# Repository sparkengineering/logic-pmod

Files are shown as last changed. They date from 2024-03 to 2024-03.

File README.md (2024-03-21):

# logic-pmod




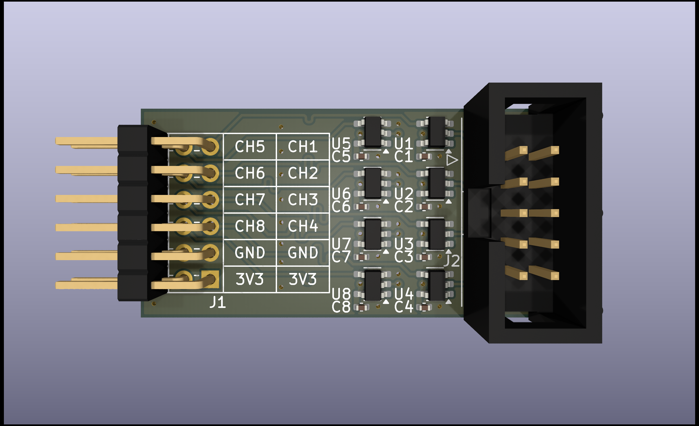
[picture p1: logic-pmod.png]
3D render of this Pmod level shifter board


## Description

Logic level shifter with Digilent Pmod™ interface for use as logic analyzer.

- 8 fixed direction, length tuned, level shifting channels
- Up/down translation from 1.8V, 2.5V, 5V to 3.3V
- Bus Pirate probe cable compatible 10-pin connector

## Contents

| File | Description |
|---|---|
| [logic-pmod.pdf](./logic-pmod.pdf) | Schematic in PDF format |
| [logic-pmod.csv](./logic-pmod.csv) | BOM in CSV format |
| [logic-pmod.png](./logic-pmod.png) | PCB 3D render |
| | |
| [logic-pmod.kicad_pro](./logic-pmod.kicad_pro) | KiCad 8.0.0 project |
| [logic-pmod.kicad_pcb](./logic-pmod.kicad_pcb) | KiCad 8.0.0 PCB |
| [logic-pmod.kicad_sch](./logic-pmod.kicad_sch) | KiCad 8.0.0 schematic |

## Probe Pinout

| Pin | Color  | Net  |
|-----|---|---|
| 1 | Brown  | GND  |
| 2 | Red | +3V3 |
| | | |
| 3 | Orange | CH5  |
| 4 | Yellow | CH1  |
| 5 | Green  | CH6  |
| 6 | Blue | CH2  |
| 7 | Purple | CH7  |
| 8 | Grey | CH3  |
| 9 | White  | CH8  |
|  10 | Black  | CH4  |

## Further Reading

- FPGA Logic Analyzer and GUI [^1]
- Small footprint and configurable embedded FPGA logic analyzer [^2]
- Integrated Logic Analyzer (ILA) [^3]

[^1]: https://github.com/lekgolo167/enxor-logic-analyzer
[^2]: https://github.com/enjoy-digital/litescope
[^3]: https://www.xilinx.com/products/intellectual-property/ila.html

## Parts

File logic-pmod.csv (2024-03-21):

Reference | Value | Footprint | Qty | DNP | MFG | MPN | OC_Mouser | OC_LCSC
C1,C2,C3,C4,C5,C6,C7,C8 | 100nF | Capacitor_SMD:C_0402_1005Metric | 8 |  | Murata Electronics | GRM155R61A104JA01D | 81-GRM155R61A104JA1D | C177144
J1 | Conn_02x06_Odd_Even | logic-pmod:PinHeader_2x06_P2.54mm_Horizontal | 1 |  | TE Connectivity | 826634-6 | 571-826634-6 | ~
J2 | Conn_02x05_Odd_Even | logic-pmod:IDC-Header_2x05_P2.54mm_Vertical | 1 |  | TE Connectivity | 1761681-3 | 571-1761681-3 | C573025
U1,U2,U3,U4,U5,U6,U7,U8 | SN74LV1T34DBV | Package_TO_SOT_SMD:SOT-23-5 | 8 |  | Texas Instruments | SN74LV1T34QDBVRQ1 | 595-N74LV1T34QDBVRQ1 | ~

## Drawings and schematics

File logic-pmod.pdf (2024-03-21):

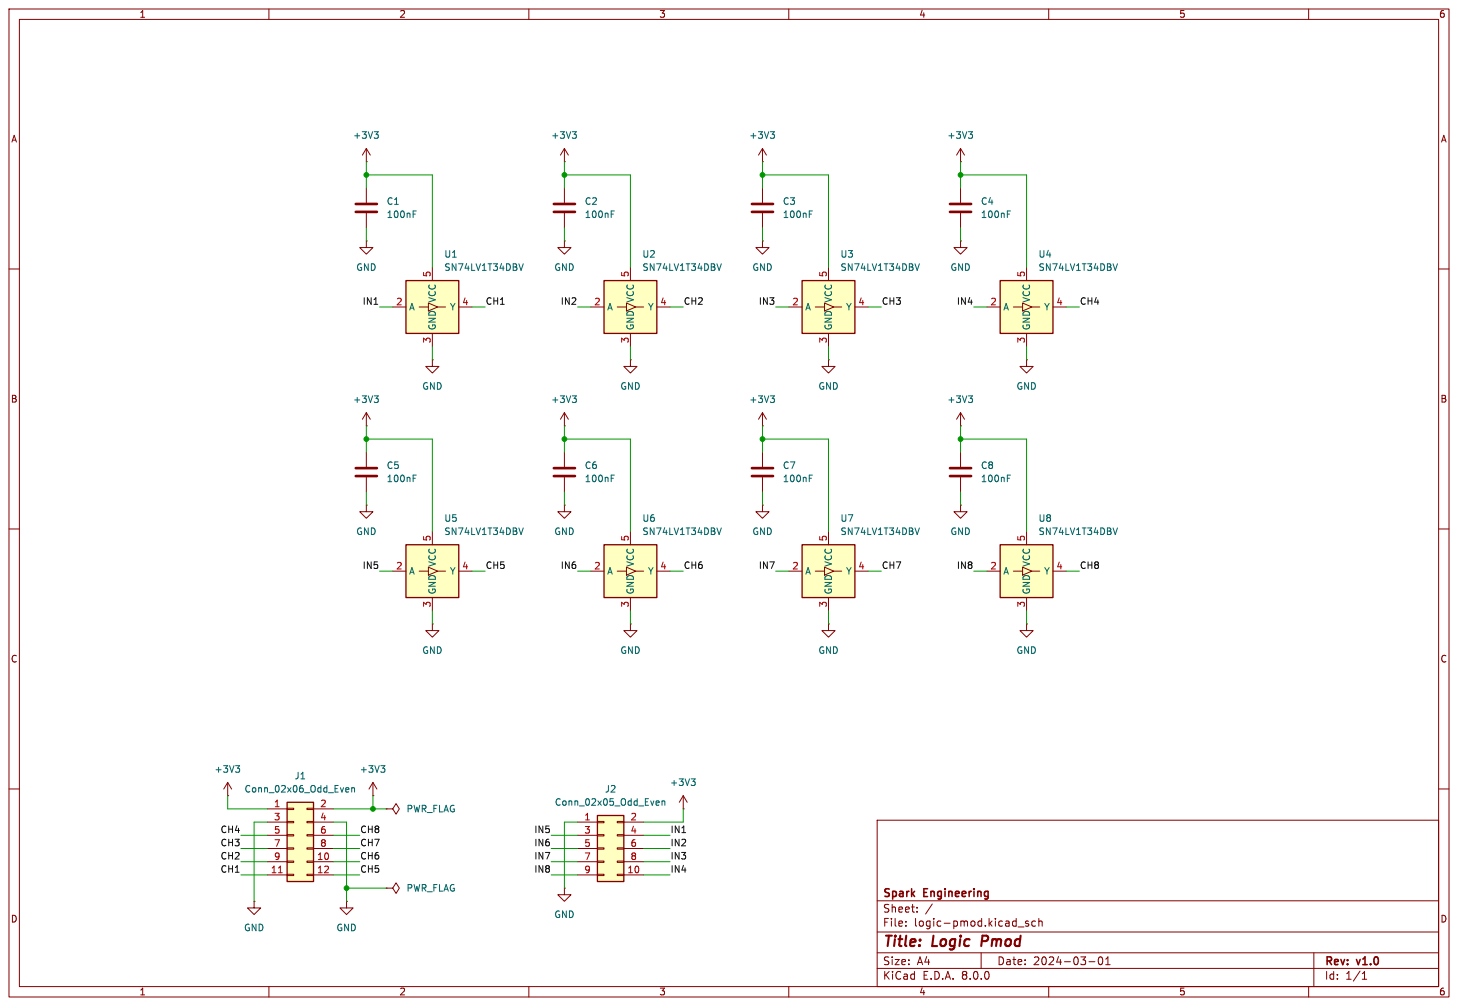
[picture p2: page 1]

5 U7SN74LV1T34DBV GND GND GND GND

Id: 1/1 Title: Logic Pmod

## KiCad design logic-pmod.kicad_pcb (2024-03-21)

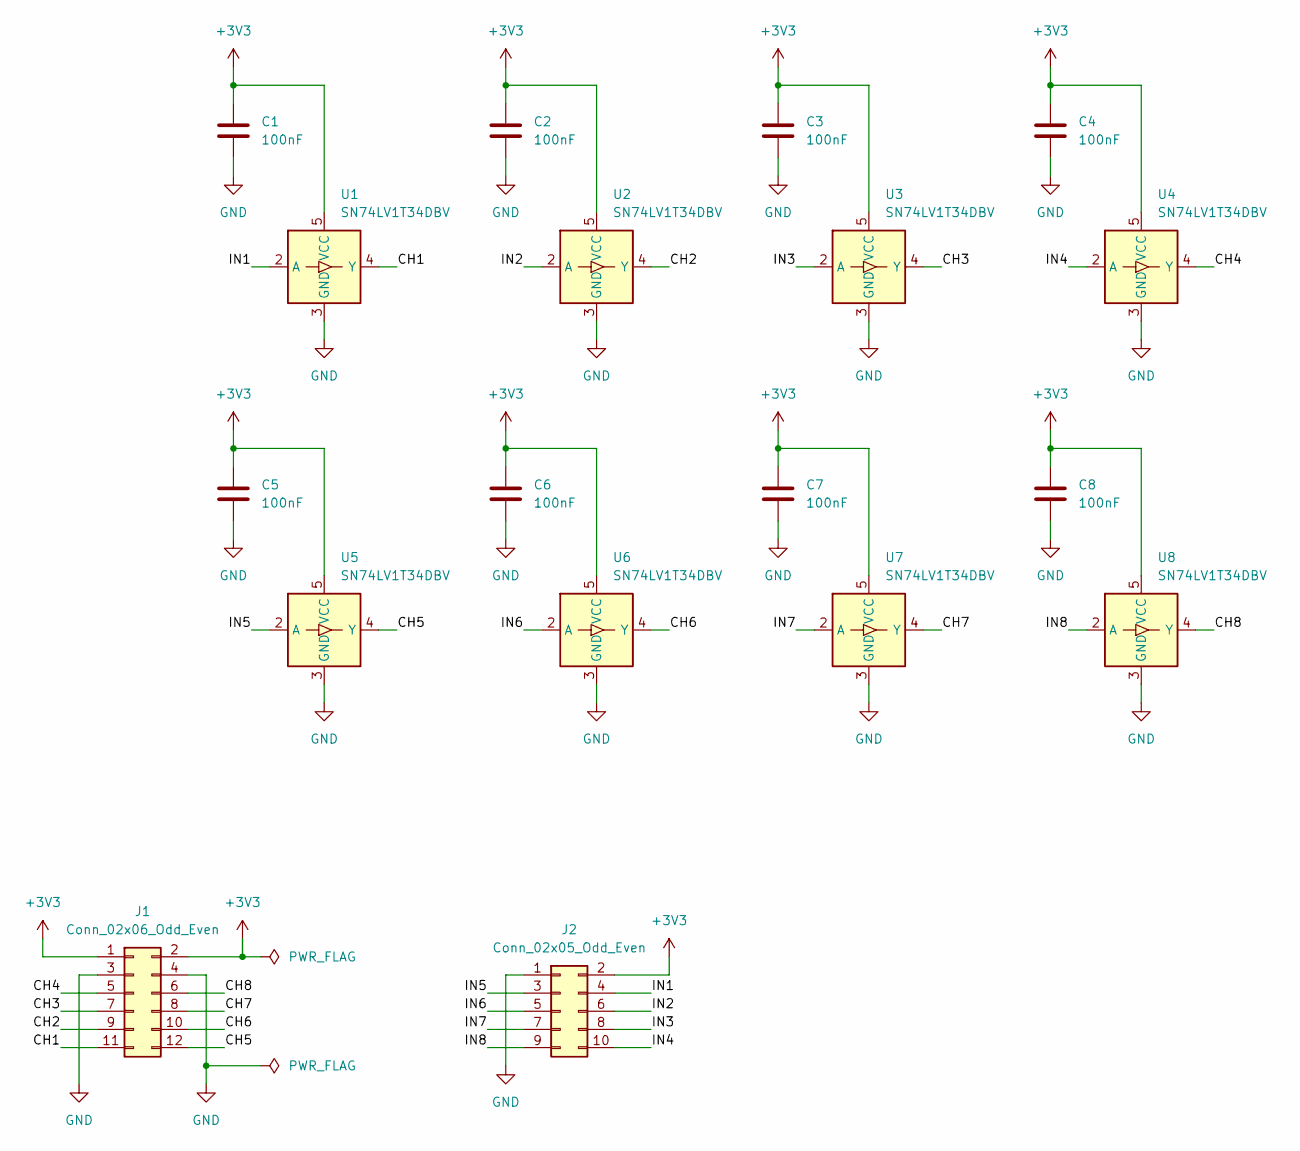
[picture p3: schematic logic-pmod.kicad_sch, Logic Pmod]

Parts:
C1, C2, C3, C4, C5, C6, C7, C8: 100nF; C_0402_1005Metric; MPN GRM155R61A104JA01D
J1: Conn_02x06_Odd_Even; PinHeader_2x06_P2.54mm_Horizontal; MPN 826634-6
J2: Conn_02x05_Odd_Even; IDC-Header_2x05_P2.54mm_Vertical; MPN 1761681-3
U1, U2, U3, U4, U5, U6, U7, U8: SN74LV1T34DBV; SOT-23-5; MPN SN74LV1T34QDBVRQ1

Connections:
+3V3: C1.1, C2.1, C3.1, C4.1, C5.1, C6.1, C7.1, C8.1, J1.1, J1.2, J2.2, U1.5 (VCC), U2.5 (VCC), U3.5 (VCC), U4.5 (VCC), U5.5 (VCC), U6.5 (VCC), U7.5 (VCC), U8.5 (VCC)
/CH1: J1.11, U1.4 (Y)
/CH2: J1.9, U2.4 (Y)
/CH3: J1.7, U3.4 (Y)
/CH4: J1.5, U4.4 (Y)
/CH5: J1.12, U5.4 (Y)
/CH6: J1.10, U6.4 (Y)
/CH7: J1.8, U7.4 (Y)
/CH8: J1.6, U8.4 (Y)
/IN1: J2.4, U1.2 (A)
/IN2: J2.6, U2.2 (A)
/IN3: J2.8, U3.2 (A)
/IN4: J2.10, U4.2 (A)
/IN5: J2.3, U5.2 (A)
/IN6: J2.5, U6.2 (A)
/IN7: J2.7, U7.2 (A)
/IN8: J2.9, U8.2 (A)
GND: C1.2, C2.2, C3.2, C4.2, C5.2, C6.2, C7.2, C8.2, J1.3, J1.4, J2.1, U1.3 (GND), U2.3 (GND), U3.3 (GND), U4.3 (GND), U5.3 (GND), U6.3 (GND), U7.3 (GND), U8.3 (GND)

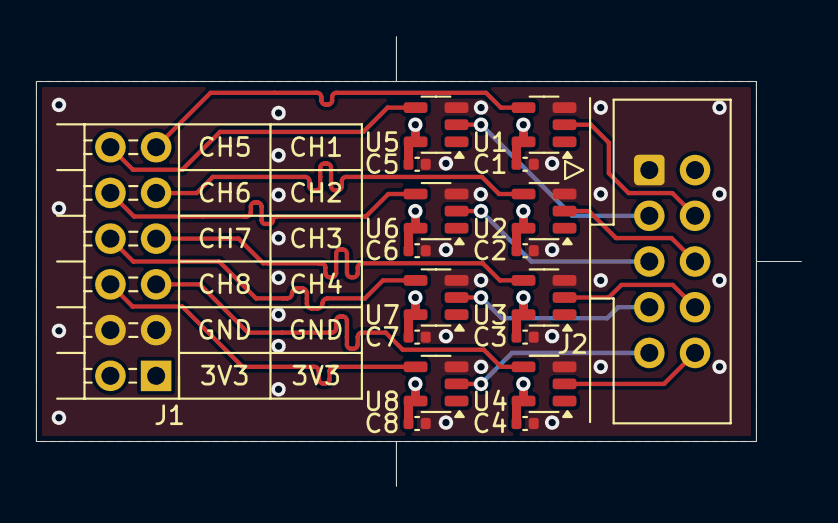
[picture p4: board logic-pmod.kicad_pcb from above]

Board: 4 copper layers, 40.0 x 20.0 mm, 18 parts (0 on the bottom side), 18 nets.
